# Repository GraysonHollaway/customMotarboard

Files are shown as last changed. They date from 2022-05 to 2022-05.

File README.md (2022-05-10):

# Custom Motarboard
Gerber and KiCad files used to make a custom mortarboard decoration for graduation.
This custom PCB sits on top of your gaduation cap and spells out 'ECE OSU' in amber LEDs using a custom designed state machine. 
The clock was implemented with a monostable 555 timer producing an approxamate square wave with tau on the order of 100 milliseconds 
The LEDs are contolled with an NPN BJT such that the digital and analog sections of the circuit are seperated.

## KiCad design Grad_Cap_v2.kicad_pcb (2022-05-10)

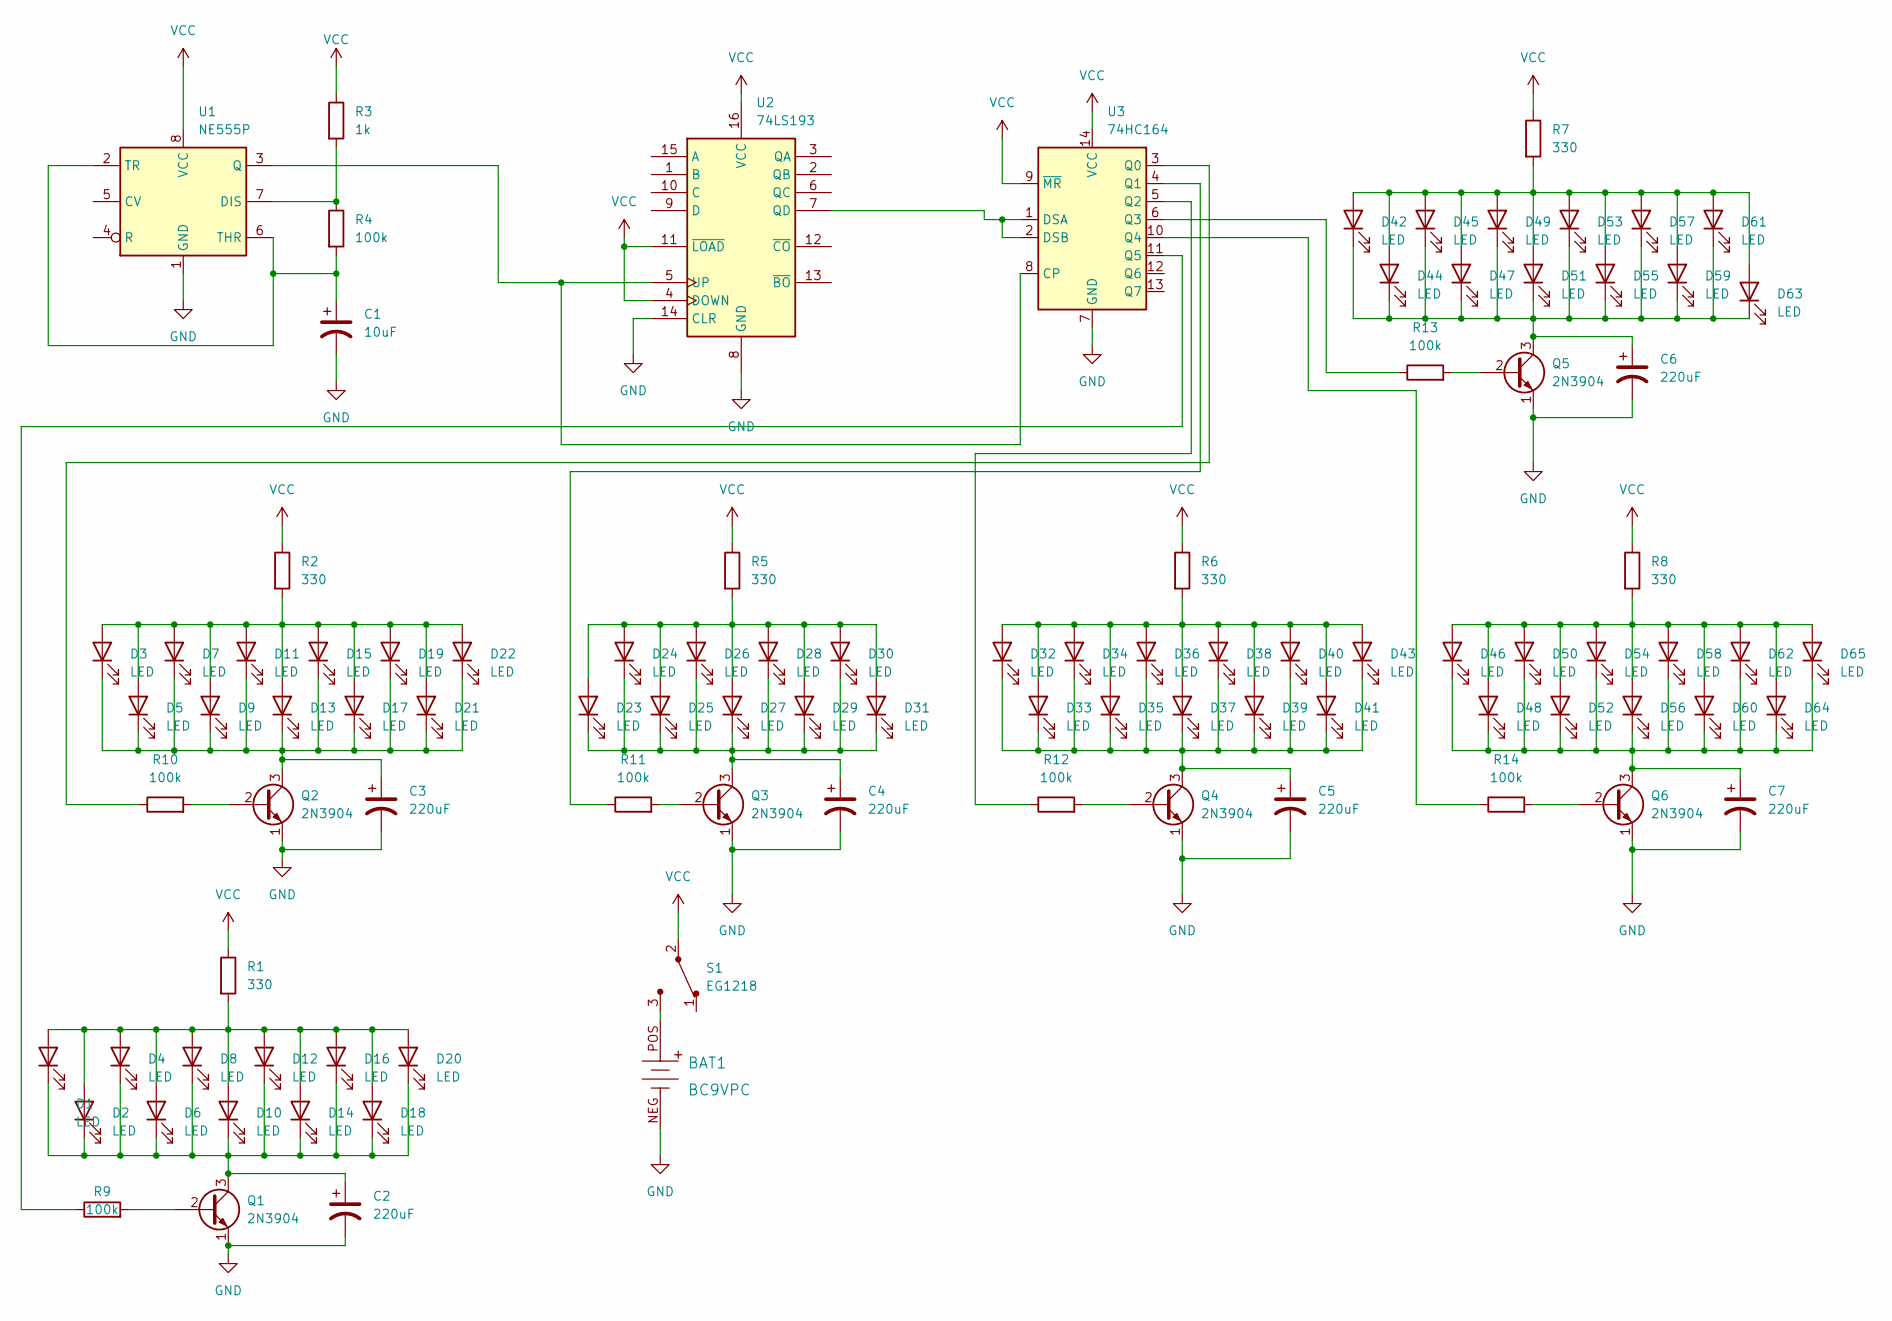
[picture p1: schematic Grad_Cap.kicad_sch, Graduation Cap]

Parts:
BAT1: BC9VPC; Battery_Holder_9V_BC9VPC-ND; MPN BC9VPC; Digi-Key_PN BC9VPC-ND
C1: 10uF; CP_Radial_D4.0mm_P2.00mm
C2, C3, C4, C5, C6, C7: 220uF; CP_Radial_D4.0mm_P2.00mm
D1, D2, D3, D4, D5, D6, D7, D8, D9, D10, D11, D12, D13, D14, D15, D16, D17, D18, D19, D20, D21, D22, D23, D24, D25, D26, D27, D28, D29, D30, D31, D32, D33, D34, D35, D36, D37, D38, D39, D40, D41, D42, D43, D44, D45, D46, D47, D48, D49, D50, D51, D52, D53, D54, D55, D56, D57, D58, D59, D60, D61, D62, D63, D64, D65: LED; LED_D5.0mm
Q1, Q2, Q3, Q4, Q5, Q6: 2N3904; TO-92_Inline
R1, R2, R5, R6, R7, R8: 330; R_Axial_DIN0309_L9.0mm_D3.2mm_P12.70mm_Horizontal
R3: 1k; R_Axial_DIN0309_L9.0mm_D3.2mm_P12.70mm_Horizontal
R4, R9, R10, R11, R12, R13, R14: 100k; R_Axial_DIN0309_L9.0mm_D3.2mm_P12.70mm_Horizontal
S1: EG1218; Switch_Slide_11.6x4mm_EG1218; MPN EG1218; Digi-Key_PN EG1903-ND
U1: NE555P; DIP-8_W7.62mm
U2: 74LS193; DIP-16_W7.62mm_Socket
U3: 74HC164; DIP-14_W7.62mm

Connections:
GND: BAT1.NEG, C1.2, C2.2, C3.2, C4.2, C5.2, C6.2, C7.2, Q1.1 (E), Q2.1 (E), Q3.1 (E), Q4.1 (E), Q5.1 (E), Q6.1 (E), U1.1 (GND), U2.8 (GND), U2.14 (CLR), U3.7 (GND)
unnamed: BAT1.POS, S1.3
unnamed: C1.1, R4.2, U1.2 (TR), U1.6 (THR)
unnamed: C2.1, D1.1 (K), D2.1 (K), D4.1 (K), D6.1 (K), D8.1 (K), D10.1 (K), D12.1 (K), D14.1 (K), D16.1 (K), D18.1 (K), D20.1 (K), Q1.3 (C)
unnamed: C3.1, D3.1 (K), D5.1 (K), D7.1 (K), D9.1 (K), D11.1 (K), D13.1 (K), D15.1 (K), D17.1 (K), D19.1 (K), D21.1 (K), D22.1 (K), Q2.3 (C)
unnamed: C4.1, D23.1 (K), D24.1 (K), D25.1 (K), D26.1 (K), D27.1 (K), D28.1 (K), D29.1 (K), D30.1 (K), D31.1 (K), Q3.3 (C)
unnamed: C5.1, D32.1 (K), D33.1 (K), D34.1 (K), D35.1 (K), D36.1 (K), D37.1 (K), D38.1 (K), D39.1 (K), D40.1 (K), D41.1 (K), D43.1 (K), Q4.3 (C)
unnamed: C6.1, D42.1 (K), D44.1 (K), D45.1 (K), D47.1 (K), D49.1 (K), D51.1 (K), D53.1 (K), D55.1 (K), D57.1 (K), D59.1 (K), D61.1 (K), D63.1 (K), Q5.3 (C)
unnamed: C7.1, D46.1 (K), D48.1 (K), D50.1 (K), D52.1 (K), D54.1 (K), D56.1 (K), D58.1 (K), D60.1 (K), D62.1 (K), D64.1 (K), D65.1 (K), Q6.3 (C)
unnamed: D1.2 (A), D2.2 (A), D4.2 (A), D6.2 (A), D8.2 (A), D10.2 (A), D12.2 (A), D14.2 (A), D16.2 (A), D18.2 (A), D20.2 (A), R1.2
unnamed: D3.2 (A), D5.2 (A), D7.2 (A), D9.2 (A), D11.2 (A), D13.2 (A), D15.2 (A), D17.2 (A), D19.2 (A), D21.2 (A), D22.2 (A), R2.2
unnamed: D23.2 (A), D24.2 (A), D25.2 (A), D26.2 (A), D27.2 (A), D28.2 (A), D29.2 (A), D30.2 (A), D31.2 (A), R5.2
unnamed: D32.2 (A), D33.2 (A), D34.2 (A), D35.2 (A), D36.2 (A), D37.2 (A), D38.2 (A), D39.2 (A), D40.2 (A), D41.2 (A), D43.2 (A), R6.2
unnamed: D42.2 (A), D44.2 (A), D45.2 (A), D47.2 (A), D49.2 (A), D51.2 (A), D53.2 (A), D55.2 (A), D57.2 (A), D59.2 (A), D61.2 (A), D63.2 (A), R7.2
unnamed: D46.2 (A), D48.2 (A), D50.2 (A), D52.2 (A), D54.2 (A), D56.2 (A), D58.2 (A), D60.2 (A), D62.2 (A), D64.2 (A), D65.2 (A), R8.2
unnamed: Q1.2 (B), R9.2
unnamed: Q2.2 (B), R10.2
unnamed: Q3.2 (B), R11.2
unnamed: Q4.2 (B), R12.2
unnamed: Q5.2 (B), R13.2
unnamed: Q6.2 (B), R14.2
unnamed: R3.2, R4.1, U1.7 (DIS)
unnamed: R9.1, U3.11 (Q5)
unnamed: R10.1, U3.3 (Q0)
unnamed: R11.1, U3.4 (Q1)
unnamed: R12.1, U3.5 (Q2)
unnamed: R13.1, U3.6 (Q3)
unnamed: R14.1, U3.10 (Q4)
unnamed: U1.3 (Q), U2.5 (UP), U3.8 (CP)
unnamed: U2.7 (QD), U3.1 (DSA), U3.2 (DSB)
VCC: R1.1, R2.1, R3.1, R5.1, R6.1, R7.1, R8.1, S1.2, U1.8 (VCC), U2.4 (DOWN), U2.11 (~LOAD), U2.16 (VCC), U3.9 (~MR), U3.14 (VCC)

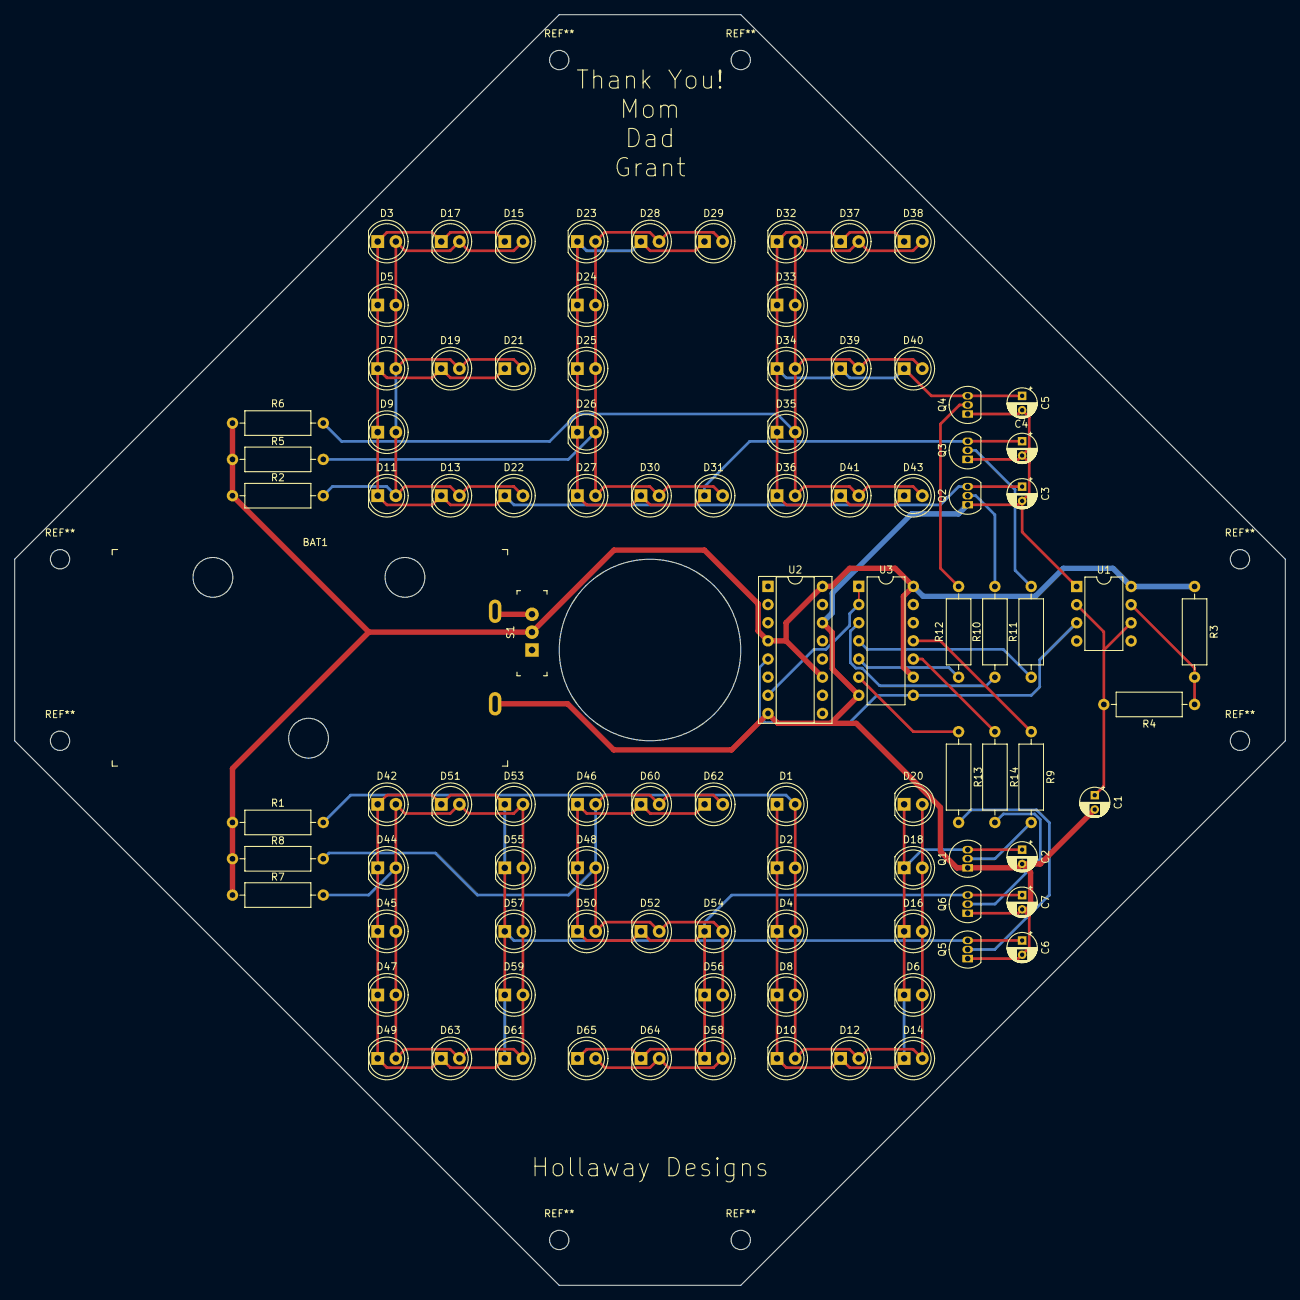
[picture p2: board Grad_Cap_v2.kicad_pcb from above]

Board: 2 copper layers, 177.8 x 177.8 mm, 97 parts (0 on the bottom side), 31 nets.

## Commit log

2022-05-10 All Gerber files added
    [Grad_Cap_v2-B_Cu.gbl, Grad_Cap_v2-B_Mask.gbs, Grad_Cap_v2-B_Paste.gbp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]
2022-05-10 Add files via upload
    KiCad files added
    [Grad_Cap.kicad_sch, Grad_Cap_v2.kicad_pcb]
